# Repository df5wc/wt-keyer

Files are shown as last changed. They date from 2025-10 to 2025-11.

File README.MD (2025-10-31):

# Walkie-Talkie Keyer

So, hier isser: Der Walkie-Talkie Keyer. Das Projekt, an dem ich die letzten
Wochen nebenher rumgepusselt habe. Es ist eine komplette Hardware zum Betrieb
eines Handfunkgeräts als CW Station.

## Noch nie gestellte Fragen und ein paar Antworten:

### Was macht das Gerät?

CW über FM.

### Das kann ein Piepser, den ich ans Funkgerät halte. Wieso eine extra Hardware?

Der Walkie-Talkie Keyer übernimmt die komplette Steuerung. Er schaltet beim
ersten Zeichen das Handfunkgerät auf Sendung, generiert lokal einen Mithörton
und gibt die Morsezeichen auf das Funkgerät um wenige 100ms zeitverzögert aus.
Damit hat das Funkgerät Zeit, auf Sendung zu schalten. Mit dem Walkie-Talkie
Keyer ist CW mit einer Handfunke ähnlich komfortabel wie mit einem Gerät, das
CW native unterstützt: Einfach losmorsen. Das Gerät schaltet automatisch auf
Sendung und nach dem letzten Zeichen wieder zurück.

### Wofür braucht man das?

Ich habe es primär gebaut um auf dem Congress TOTA in CW machen zu können,
weil ich dort vermutlich nur ein Handfunkgerät haben werde. Der Walkie-Talkie
Keyer funktioniert aber nicht nur im Amateurfunk, sondern kann auch einfache
PMR Funkgeräte ansteuern und eignet sich deshalb auch zur Ausbildung oder als
Spaßprojekt für Kids. Der Keyer kann im Prinzip auch "große" Funkgeräte
ansteuern, solange diese PTT gegen Masse schalten und dafür keine hohen
Ströme/Spannungen notwendig sind.

### Gab's das nicht schon mal?

Ja, das gab's schon mal. Burkhard John (DK5JG) hat 2006 eine ähnliches Projekt
vorgestellt, den "FM-Keyer". Von diesem Gerät stammen einige der Ideen.
Schaltung, Software und Board des Walkie-Talkie Keyers sind aber komplett neu
und von mir.

### Paddle oder Handtaste?

Der Keyer kann beides, mit Handtaste ist aber keine Konfiguration möglich. Da
alle Einstellungen (bis auf "Handtaste oder Paddle") ausfallsicher gespeichert
werden, sollte das aber kein großes Problem sein. Nachdem die Konfiguration
mit einem Paddle durchgeführt wurde, kann mit genau diesen Einstellungen auch
eine Handtaste verwendet werden.

### Wie wird eine Handtaste erkannt?

Für ein Paddle wird ein 3,5 mm Stereo Klinkenstecker verwendet, für eine
Handtaste derselbe Stecker in Mono. Durch den Mono Stecker wird das rechte
Paddle ("Dah") an Masse gelegt. Das erkennt der Keyer beim Start und schaltet
direkt auf Handtaste um. Alternativ kann das rechte Paddle beim Start gedrückt
werden, oder mit dem "SK" Kommando (siehe unten) von Paddle auf Handtaste
umgeschaltet werden.

Die Einstellung "Handtaste" bleibt erhalten, bis der Keyer stromlos gemacht
wird. Ein Rückschalten durch Kommando ist nicht möglich.

### Wie bediene ich den Keyer?

Der Keyer benötigt externe 5V aus einem USB Port (Handy oder Power Bank). Er
wird auf der einen Seite mit dem Handfunkgerät verbunden. Auf der anderen
Seite wird die Taste angeschlossen. Neben der Einstellung für die Lautstärke
an der Seite gibt es an der Unterseite noch zwei Potis mit denen die Pegel für
das Handfunkgerät eingestellt werden können. Sie sollten bei der ersten
Inbetriebnahme auf jeweils 1/4 im Uhrzeigersinn eingestellt und dann nach
Gehör justiert werden. Bei Verwendung eines anderen Funkgeräts oder großen
Änderungen der Tonhöhe kann eine Nachjustierung notwendig sein.

Danach kann im Prinzip schon losgemorst werden. Zur Einstellung gibt es die
Taste &lt;Cmd&gt;. Wenn sie gedrückt und gehalten wird, können dem Keyer
Kommandos in CW gegeben werden. Hier ist die Liste der Kommandos:

* D?             query the tx delay
* Dnnn           set tx delay in ms
* IA             activate iambic A
* IB             activate iambic B
* IP             activate plain iambic mode
* M?1            query cw memory 1
* M?2            query cw memory 2
* M1...          program cw memory 1
* M2...          program cw memory 2
* O?             query tx off delay in dits
* Onn            set tx off delay in dits
* SK             switch to straight key
* SWD            disable paddle swap
* SWE            enable paddle swap
* T?             query the tone frequency
* TMD            disable training mode (TX)
* TME            enable training mode (no TX)
* Tnnn           set a tone frequency
* V?             query the software version number
* W?             query the keyer speed
* Wnn            set the keyer speed in wpm

Die Kommandos werden jeweils mit einem hohen Ton quittiert, wenn sie
erfolgreich ausgeführt wurden. Bei einem Fehler (oder einem unbekannten
Kommando) erfolgt eine Fehlerquittung (niedriger Ton).

Alle Einstellungen werden ausfallsicher gespeichert und stehen deshalb nach
dem nächsten Start genau so wieder zur Verfügung.

### Wie funktioniert das mit den CW Speichern?

Der Keyer verfügt über zwei Speicherplätze für Nachrichten in Morsecode. Diese
können über die Kommandos "M1" und "M2" programmiert und mit den Tasten
&lt;1&gt; und &lt;2&gt; abgerufen werden. Während ein Speichertext ausgegeben
wird, kann mittels Druck auf einen beliebigen Knopf oder Betätigung der
Morsetaste die Ausgabe abgebrochen werden.

Für die Programmierung wird &lt;Cmd&gt; gedrückt und "M1" oder "M2" mit dem
Paddle gegeben. Dann folgt der zu speichernde Text. Eine Pause von mindestens
2 Sekunden beendet die Eingabe mit einem Quittungston.

Um Speicherplatz zu sparen, werden alle Zeiten auf volle Vielfache der für ein
"Dit" benötigten Zeit gerundet. Der benötigte Speicherplatz pro Element mit
folgender Pause (also "Dit" oder "Dah") beträgt 1 Byte. Insgesamt stehen etwa
200 Bytes pro Speicherplatz zur Verfügung. Wird die maximale Länge eines
Speichers bei der Eingabe überschritten, erfolgt eine Fehlerquittung und der
Text wird nicht gespeichert. Die Programmierung kann auch durch Loslassen der
&lt;Cmd&gt; Taste vorzeitig abgebrochen werden (z.B. bei Fehltastung). Der
bereits gespeicherte Text bleibt dann erhalten.

### Wieso erfolgt die Tonausgabe des Handfunkgeräts über den Keyer?

Das ist bei Handfunkgeräten mit Kenwood "Norm" für den Anschluß eines externen
Mikrofons leider zwingend. Bei dieser Beschaltung werden zwei Stecker
verwendet, einer für Mikrofon/PTT, der andere für den Lautsprecher. Der
Stecker für Mikrofon/PTT führt aber keine Masse! Will man also PTT gegen Masse
schalten, muss zwingend auch der Lautsprecheranschluß verwendet werden. Dadurch
wird aber der interne Lautsprecher des Geräts abgeschaltet. Folglich muss die
Ausgabe über das angeschlossene Gerät erfolgen.

Wird eine andere Anschlußbeschaltung verwendet (von mir nicht getestet), dann
kann - falls das gewünscht ist - der "Speaker" Eingang am DIN Stecker des
Keyers einfach auf Masse gelegt, und der interne Lautsprecher des Geräts
verwendet werden. Der Mithörton kommt dann aus dem Lautsprecher des Keyers,
das Empfangssignal aus dem Lautsprecher des Funkgeräts.

### Welche Funkgeräte wurden getestet?

Ich habe den Keyer mit meinem Wouxun KG-UV6D und mit zwei verschiedenen PMR
Funkgeräten getestet. Alle diese Geräte hatten die Kenwood Anschlußbelegung.
Andere Anschlüsse sollten funktionieren, wenn PTT gegen Masse geschaltet wird
und keine hohen Ströme fliessen. Wenn keine Ausgabe des Empfangssignals über
die Keyer Hardware erfolgen soll, dann ist der entsprechende Eingang des
Keyers am DIN Stecker auf Masse zu legen.

### Ich habe ein Problem, wieso kann ich kein Issue anlegen?

Das Repository auf Github dient nur der Veröffentlichung, nicht der
Entwicklung. Für die Entwicklung wird ein anderes Repository verwendet.
Deshalb können auf Github keine Issues angelegt werden. Bei Problemen bitte
ich darum, mich per Mail zu kontaktieren.

### Gibt es bekannte Probleme?

Beim Prototyp hatte ich teilweise Probleme mit Einstrahlungen durch das
Handfunkgerät. Ich empfehle, ein abgeschirmtes Kabel für die Verbindung zum
Funkgerät zu verwenden und evtl. die Ferritperlen auf dem Board gegen kleine
Induktivitäten auszutauschen und/oder an der Stelle noch mit 100pF
abzublocken. Sobald mehr Erfahrungen vorliegen werde ich ggf. entsprechende
Änderungen der Schaltung vornehmen.

Die beiden Trimmer RV1 und RV2 werden von der Unterseite des Boards aus
bedient und haben deshalb die falsche Drehrichtung: Rechtsanschlag ist
Minimum, Linksanschlag ist Maximum.

### Ich kann mir das nicht vorstellen. Wie sieht der Keyer denn aus?

Hier sind Bilder vom aufgebauten Keyer und von einem kompletten Setup:

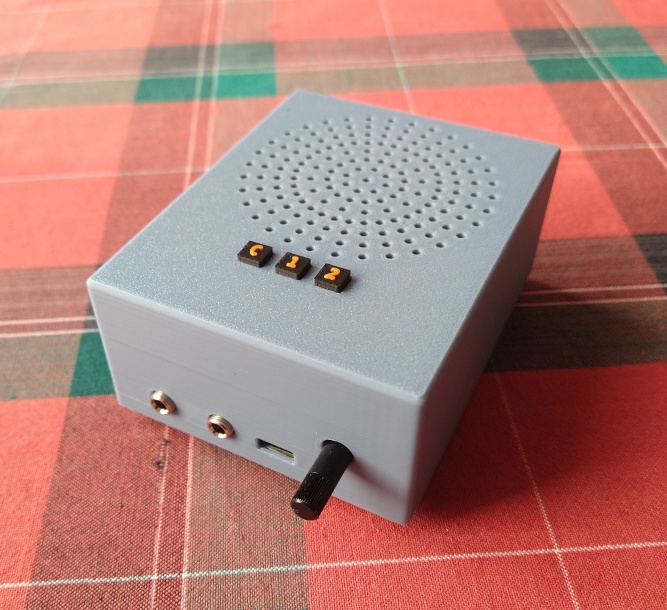
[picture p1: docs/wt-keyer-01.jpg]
Keyer

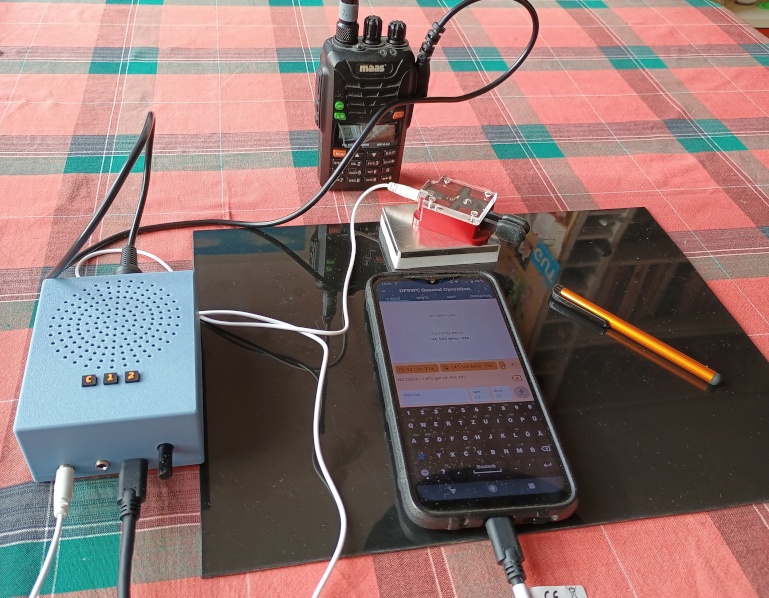
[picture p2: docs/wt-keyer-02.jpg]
Setup


### Wo gibt's den Keyer zu kaufen?

Gar nicht (zumindest bei mir). Von mir gibt es

  - den Schaltplan,
  - einen PCB Entwurf,
  - die Software,
  - OpenSCAD Sourcen und STL Datei für das Gehäuse,
  - und eine minimale Doku

auf GitHub. Mit dabei ist eine Teileliste mit (größtenteils und ohne Garantie)
Reichelt Bestellnummern.

Wenn genug Interesse besteht, kann ich nochmals einen Satz Platinen fertigen
lassen und - solange übrig sind - welche abgeben. Ggf. mit programmierter AVR
CPU. Ich vertreibe aber keine Fertiggeräte oder Bausätze. Falls das jemand
machen will habe ich aber nichts dagegen.

### Ok, ich will bauen! Wie lege ich los?

Hier gibt es mehr Infos zum Aufbau:

* Schaltplan
* Teileliste
* Aufbauhinweise

### Was gibt es sonst zu beachten?

Die Lizenz erlaubt so ziemlich alles, bis darauf die Entwürfe als eigene
auszugeben. Für Schäden beim Nachbau übernehme ich keine Haftung.

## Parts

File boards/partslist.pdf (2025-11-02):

Please note that this list is incomplete and partially untested! Use it at your own risk!

Count | References | Description | Source | Order Number | Alternative
3 | C13,C18,C21 | Kondensator 100μF/25V | Reichelt | RAD 100/25
9 | C5,C6,C7,C8,C10,C11,C14,C15,C19 | Kondensator 100nF, MKS02 | Reichelt | MKS02-63 100N
1 | C17 | Kondensator 47nF, MKS02 | Reichelt | MKS02-63 47N
5 | C1,C2,C3,C4,C16 | Keramik-Kondensator 100nF | Reichelt | Z5U-2,5 100N
4 | C9,C12,C20,C22 | Keramik-Kondensator 10nF | Reichelt | Z5U-2,5 10N
1 | Conn1 | Stiftleiste 2x3, RM 2,54 | Reichelt | MPE 087-2-006 | BKL 10120172
1 | F1 | Keramik-Resonator 8MHz | Reichelt | CST 8,00
8 | FB1,FB2,FB3,FB4,FB5,FB6,FB7,FB8 | Ferritperle | Aliexpress | https://de.aliexpress.com/item/10000063621565.html
1 | IC1 | AVR ATMega8 PDIP-28 | Reichelt | ATMEGA 8L8 DIP | ATMEGA 8-16 DIP
1 | IC2 | LM386-1, NF Verstärker IC | Reichelt | LM 386 DIP
1 | J1 | Printstecker, gerade, 2-polig | Reichelt | PSS 254/3G
1 | J2 | Printstecker, gerade, 3-polig | Reichelt | PSS 254/2G
2 | J3,J5 | 3.5mm Klinkenbuchse, Stereo | Reichelt | EBS 35
1 | J4 | Diodenbuchse 5-pol | Reichelt | MABP 5S
1 | J6 | USB Buchse 6-pol horizontal | Aliexpress | https://de.aliexpress.com/item/1005007419369264.html
1 | LS1 | Lautsprecher 8Ω, 0.5W | Reichelt | LSM-66F
1 | P1 | Potentiometer 10K linear | Reichelt | RK09K111-LIN10K
1 | Q1 | 2N3904 o.ä. | Reichelt | 2N 3904
4 | R1,R9,R10,R15 | Widerstand 10kΩ 5%, 250mW | Reichelt | 1/4W 10K
6 | R2,R3,R4,R5,R6,R7 | Widerstand 1.5kΩ 5%, 250mW | Reichelt | 1/4W 1,5K
1 | R8 | Widerstand 47kΩ 5%, 250mW | Reichelt | 1/4W 47K
1 | R11 | Widerstand 1kΩ 5%, 250mW | Reichelt | 1/4W 1,0K
1 | R12 | Widerstand 15kΩ 5%, 250mW | Reichelt | 1/4W 15K
1 | R13 | Widerstand 10Ω 5%, 250mW | Reichelt | 1/4W 10
1 | R14 | Widerstand 4.7kΩ 5%, 250mW | Reichelt | 1/4W 4,7K
1 | RV1 | Trimpoti 2.5kΩ linear | Reichelt | PT 10-L 2,5K
1 | RV2 | Trimpoti 500Ω linear | Reichelt | PT 10-L 500
3 | SW1,SW2,SW3 | Taster | Reichelt | DIP DTS-65K
1 | - | Kupplungs-Leergehäuse, 2-polig | Reichelt | PSK 254/2W
1 | PL4 | Kupplungs-Leergehäuse, 3-polig | Reichelt | PSK 254/3W
1 | - | Crimpkontakte | | Reichelt | PSK-KONTAKTE
1 | - | IC-Sockel 28-pol. | | Reichelt | GS 28-S
1 | - | IC-Sockel 8-pol. | | Reichelt | GS 8
1 | PL1,PL2 | Anschlußkabel Walkie-Talkie | Aliexpress | https://de.aliexpress.com/item/1005007107655534.html
1 | PL3 | DIN Stecker 5-pol 180° | Reichelt | MAS 50S
4 | - | Gummifüße 8mm | , 2mm hoch ⌀ | Aliexpress | https://de.aliexpress.com/item/1005005315398342.html
1 | - | Alternative USB Buchse, Einbau | Aliexpress | https://de.aliexpress.com/item/1005007579249404.html

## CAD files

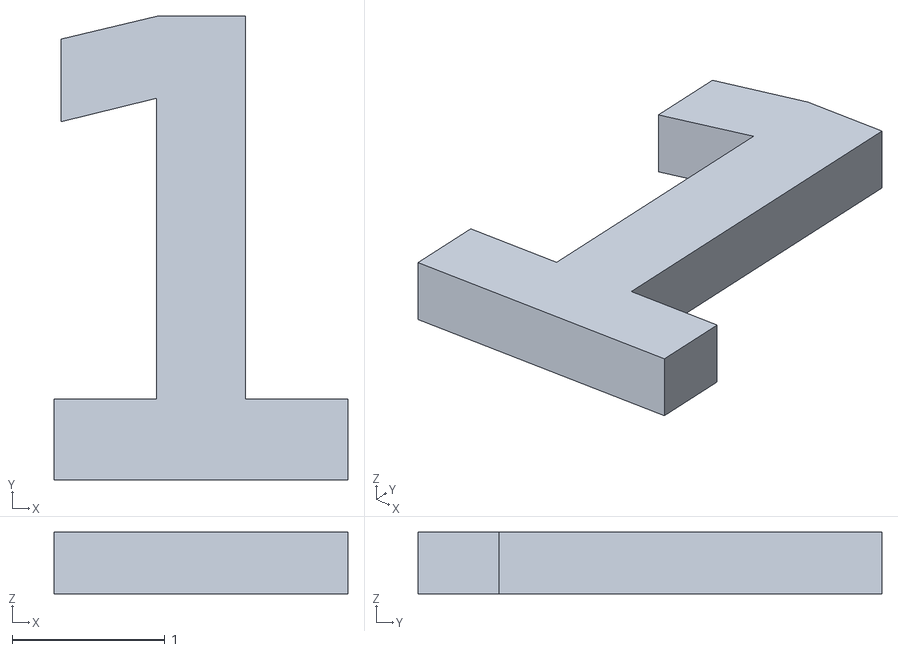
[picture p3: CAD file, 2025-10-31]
case/wt-keyer-button-label-1.stl
1.93 x 3.04 x 0.405

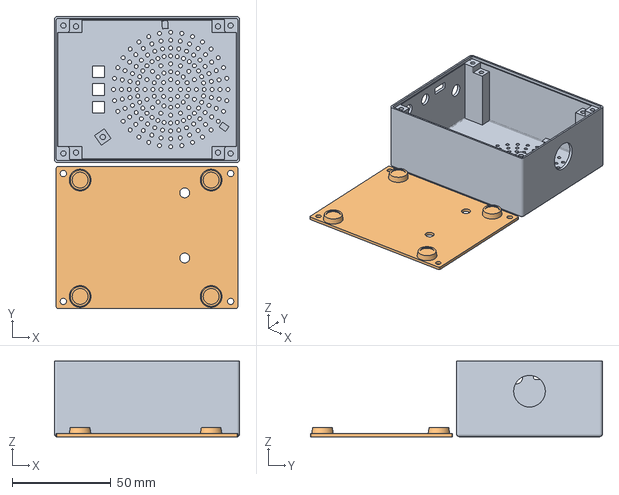
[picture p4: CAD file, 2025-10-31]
case/wt-keyer-case.3mf
94.0 x 148.0 x 38.3 mm
wt-keyer-case-upper.stl
wt-keyer-case-lower.stl

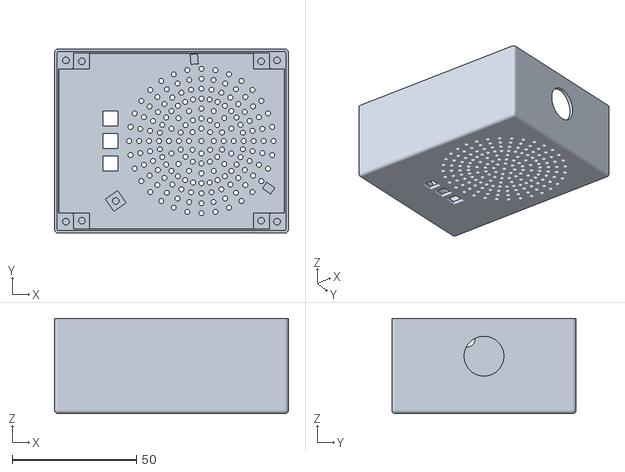
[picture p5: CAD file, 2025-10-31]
case/wt-keyer-case-upper-ext-usb.stl
94.0 x 74.0 x 38.3

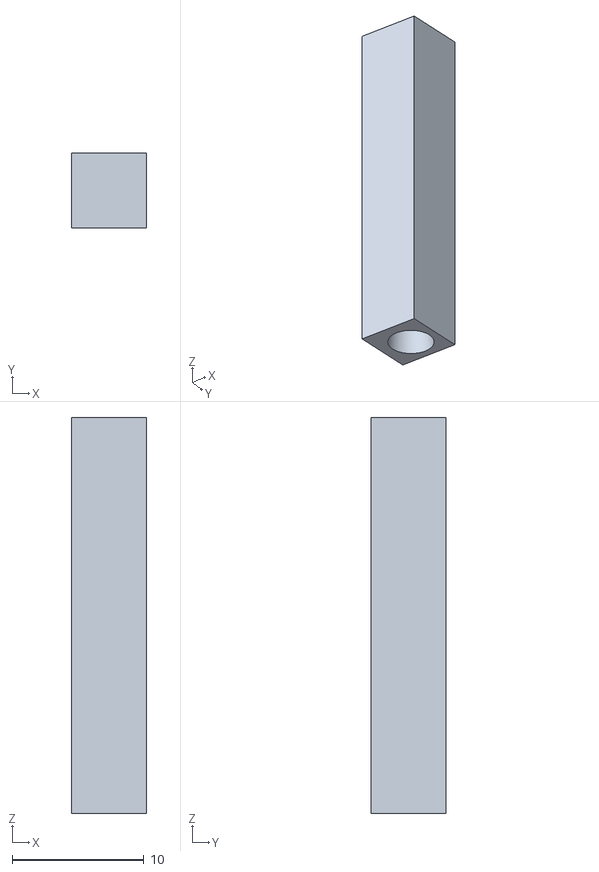
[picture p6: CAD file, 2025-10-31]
case/wt-keyer-button.stl
5.70 x 5.70 x 30.1

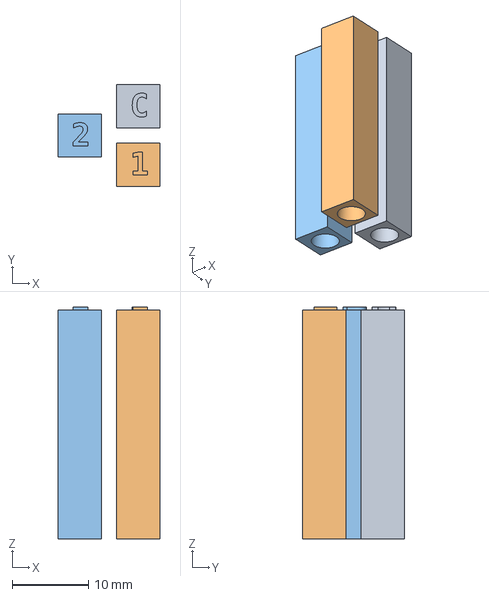
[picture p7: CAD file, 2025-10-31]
case/wt-keyer-buttons.3mf
13.4 x 13.4 x 30.5 mm
wt-keyer-case-button x 3

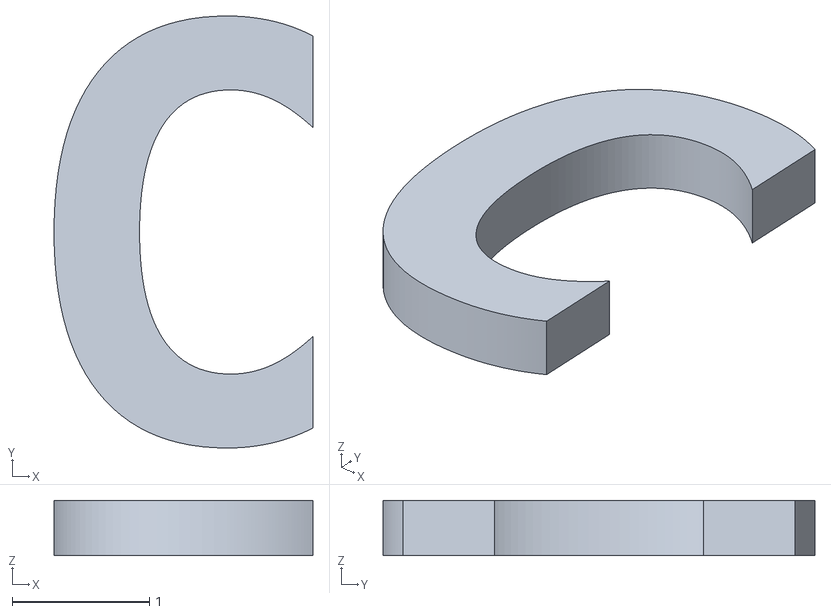
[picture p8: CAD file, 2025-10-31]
case/wt-keyer-button-label-c.stl
1.89 x 3.15 x 0.405

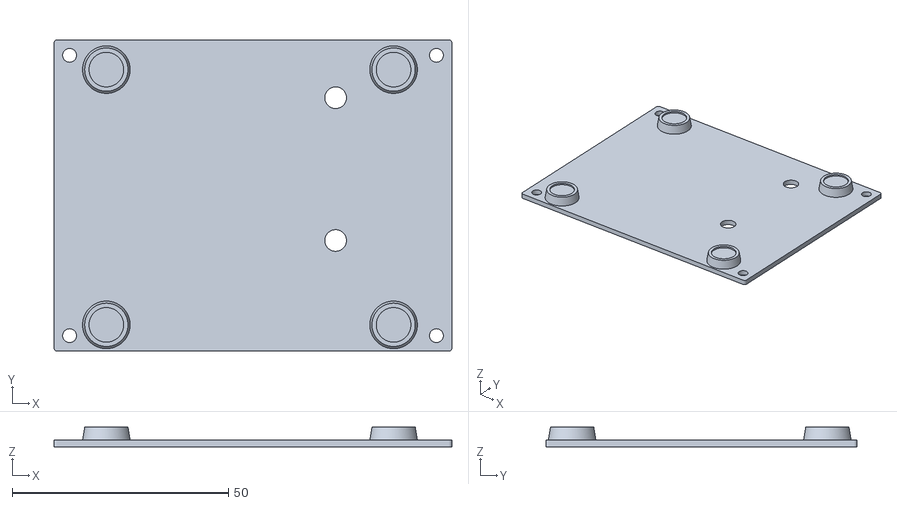
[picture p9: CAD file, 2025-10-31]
case/wt-keyer-case-lower.stl
92.0 x 72.0 x 4.60

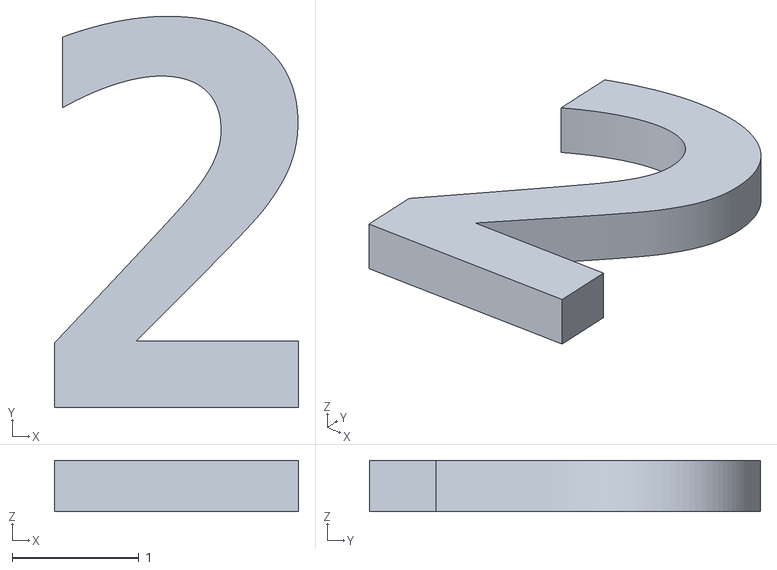
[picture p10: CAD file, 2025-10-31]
case/wt-keyer-button-label-2.stl
1.93 x 3.09 x 0.405

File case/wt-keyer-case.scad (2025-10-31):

/* Which object to generate:
 * 0 = upper part with usb breakout on the pcb
 * 1 = upper part with separate usb breakout
 * 2 = lower part
 * 3 = button prolongation
 * 4 = button label "C"
 * 5 = button label "1"
 * 6 = button label "2"
 */
what = 0;

/* Inner width of the case */
wcase = 70;

/* Inner length of the case */
lcase = 90;

/* Height of the board support: Speaker + components */
hpcbsupport = 20.5 + 11;

/* Inner height of the case.
 * Speaker + components + board + free space.
 */
hcase = hpcbsupport + 1.6 + 2;

/* Height of the lid support */
hlidsupport = hcase;

/* Gap between board and case */
gap = 0.4;

/* Radius for case edges */
rcase = 1.5;

/* Speaker diameter */
dspeaker = 66;

/* Wall width */
wall = 1.6;

/* Groove width */
groove = 0.6;

/* Screw hole diameter for self cutting screws */
mountinghole = 2.7;

/* Screw hole diameter for lid screws */
lidhole = 3.2;

/* Lower diameter of the feet */
dfoot = 11.0;

/* Height of the feet */
hfoot = 3.0;

/* Trimmer hole diameter */
trimmerhole = 5.0;

/* Button holes */
buttonhole = 6.0;

/* Hidden */
$fn  =  100;
eps  =  0.005;

/* Trimmer position #1 */
xtrimmer1 = 64.5;
ytrimmer1 = 58.0;

/* Trimmer position #2 */
xtrimmer2 = 64.5;
ytrimmer2 = 25.0;

/* Button position #1 */
xbutton1 = 20.5;
ybutton1 = 44;

/* Button position #2 */
xbutton2 = 20.5;
ybutton2 = 35;

/* Button position #3 */
xbutton3 = 20.5;
ybutton3 = 26;

/* Height of button prolongation. Switches are 9mm high, 5mm is overlap. */
hbutton = hpcbsupport + wall - 9.0 + 6.0;

/* Paddle jack position */
xpaddle = 13.0;
ypaddle = hpcbsupport - 3.05;
paddlehole = 6.5;

/* Headphone jack position */
xheadphones = 28.2;
yheadphones = hpcbsupport - 3.05;
headphoneshole = 6.5;

/* USB jack position */
xusb = 41.6;
yusb = hpcbsupport - 0.0;
usbholew = 9.0;
usbholeh = 4.0;

/* Volume control position */
xvolume = 56.0;
yvolume = hpcbsupport - 10.0;
volumehole = 7.0;

/* Rig control socket position */
xrigctrl = 35.0;
yrigctrl = hpcbsupport - 10.0;
rigctrlhole = 16.0;


module cylinder_outer(height, r1, r2){
    fudge = 1/cos(180/$fn);
    cylinder(h=height,r1=r1*fudge, r2=r2*fudge);
}

module roundedplate(x, y, z, rad = 0.75) {
    linear_extrude(height = z) {
        hull() {
            translate([0.75, 0.75, 0]) circle(r = 0.75);
            translate([x - 0.75, 0.75, 0]) circle(r = 0.75);
            translate([x - 0.75, y - 0.75, 0]) circle(r = 0.75);
            translate([0.75, y - 0.75, 0]) circle(r = 0.75);
        }
    }
}

module roundedcube(x, y, z, rad = 0.75) {
    hull() {
        translate([    rad,     rad,     rad]) sphere(rad);
        translate([x - rad,     rad,     rad]) sphere(rad);
        translate([    rad, y - rad,     rad]) sphere(rad);
        translate([x - rad, y - rad,     rad]) sphere(rad);
        translate([    rad,     rad, z - rad]) sphere(rad);
        translate([x - rad,     rad, z - rad]) sphere(rad);
        translate([    rad, y - rad, z - rad]) sphere(rad);
        translate([x - rad, y - rad, z - rad]) sphere(rad);
    }
}

module label(text, ha = "center", va = "center") {
    color("orange") {
        translate([0, 0, -eps]) {
            linear_extrude(0.4 + eps) {
                //text(text, size=3, font="Liberation Mono:style=Bold", halign=ha, valign=va);
                //text(text, size=3, font="Arial:style=Bold", halign=ha, valign=va);
                text(text, size=3.0, font="Bitstream Vera Sans Mono:style=Bold", halign=ha, valign=va);
            }
        }
    }
}

module usb_breakout() {
    translate([-usbholew/2, -usbholeh/2, -eps]) {
        roundedplate(usbholew, usbholeh, wall+2*eps, 1.0);
    }
}

module usb_panel_breakout() {
    l = 9;
    h = 4;
    w = 15.8;
    hole = 2.5;
    translate([-l/2, -h/2, -eps]) {
        roundedplate(l, h, wall+2*eps, 1.0);
    }
    translate([-w/2, 0, -eps]) {
        cylinder_outer(wall + 2*eps, hole/2, hole/2);
    }
    translate([w/2, 0, -eps]) {
        cylinder_outer(wall + 2*eps, hole/2, hole/2);
    }
}

module support() {
    lscrew = 12.0;
    difference() {
        union() {
            translate([0, 0, -eps]) {
                linear_extrude(height = hpcbsupport + eps) {
                    polygon(points=[
                        [-eps, -eps],
                        [-eps, 12 + gap],
                        [6 + gap, 12 + gap],
                        [6 + gap, -eps],
                    ]);
                }
            }
            intersection() {
                translate([-rcase + gap - eps, -rcase -eps, hpcbsupport - eps]) {
                    roundedplate(6 + rcase + eps, 6 + rcase + eps, hlidsupport - hpcbsupport + 0*eps);
                }
                translate([- eps, -eps, hpcbsupport - eps]) {
                    cube([6 + gap + eps, 6 + eps, hlidsupport - hpcbsupport + 2*eps]);
                }
            }
        }
        translate([3.0 + eps, 3.0 + eps, hlidsupport - lscrew]) {
            cylinder_outer(lscrew + eps, mountinghole/2, mountinghole/2);
        }
        translate([3.0 + gap + eps, 9.0 + gap + eps, hpcbsupport - lscrew]) {
            cylinder_outer(lscrew + eps, mountinghole/2, mountinghole/2);
        }
    }
}

module speakerhook() {
    translate([-1.5, 2, 0]) {
        rotate([0, 270, 180])
        linear_extrude(height = 3) {
            /* The polygon might need a height adjustment depending
             * on the speaker and the print resolution.
             */
            polygon(points=[
                [0.0, 0.0], 
                [0.0, 2.0], 
                [1.9, 2.0], 
                [3.3, 4.0], 
                [3.3, 0.0]
            ]);
        }
    }
}

module speakerscrewholder() {
    translate([-3-eps, -3-eps, -eps]) {
        difference() {
            cube([6 + 2*eps, 6 + 2*eps, 5.5 + eps]);
            translate([3.0 + eps, 3.0 + eps, 0 - eps]) {
                cylinder_outer(5.5 + 3*eps, mountinghole/2, mountinghole/2);
            }
        }
    }
}

module speakerholders() {
    rotate([0, 0, 275]) {
        translate([0, dspeaker / 2, 0]) {
            speakerhook();
        }
    }
    rotate([0, 0, 145]) {
        translate([0, dspeaker / 2, 0]) {
            speakerhook();
        }
    }
    rotate([0, 0, 35]) {
        translate([0, 9, 0]) {
            translate([0, dspeaker / 2, 0]) {
                speakerscrewholder();
            }
        }
    }
}

module speakerholes() {
    for (angle = [0:11.25:360]) {
        rotate([0, 0, angle]) {
            if (dspeaker/2 > 29+2) {
                translate([29, 0, 0]) {
                    cylinder(wall + 2*eps, r1=1, r2=1);
                }
            }
            if (dspeaker/2 > 25+2) {
                translate([25, 0, 0]) {
                    cylinder(wall + 2*eps, r1=1, r2=1);
                }
            }
            if (dspeaker/2 > 21+2) {
                translate([21, 0, 0]) {
                    cylinder(wall + 2*eps, r1=1, r2=1);
                }
            }
            if (dspeaker/2 > 17+2) {
                translate([17, 0, 0]) {
                    cylinder(wall + 2*eps, r1=1, r2=1);
                }
            }
        }
    }
    for (angle = [0:22.5:360]) {
        rotate([0, 0, angle]) {
            translate([13, 0, 0]) {
                cylinder(wall + 2*eps, r1=1, r2=1);
            }
            translate([9, 0, 0]) {
                cylinder(wall + 2*eps, r1=1, r2=1);
            }
        }
    }
    for (angle = [0:45:360]) {
        rotate([0, 0, angle]) {
            translate([5, 0, 0]) {
                cylinder(wall + 2*eps, r1=1, r2=1);
            }
        }
    }
    cylinder(wall + 2*eps, r1=1, r2=1);
}
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

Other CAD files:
case/wt-keyer-case-ext-usb.3mf
case/wt-keyer-case-upper.stl

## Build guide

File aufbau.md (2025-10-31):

# Aufbau und Inbetriebnahme des Walkie-Talkie Keyers

## Gehäuse

Das Gehäuse besteht aus:

- Dem Oberteil, das es in zwei Varianten gibt, je nachdem ob die USB Buchse auf dem Board verwendet wird, oder nicht.
- Dem Unterteil.
- Den Verlängerungen für die Drucktaster.
- Die optionale Beschriftung für die Tasten.

Ich habe das Gehäuse mit einem BambuLab P2S in PLA gedruckt. Besitzer von
BambuLab Druckern können die bereitgestellten 3mf Dateien verwenden. Diese
enthalten alle Einstellungen, wie sie von mir vorgenommen werden. Ggf. ist das
Filament noch zu korrigieren.

Hinweise für Besitzer anderer Drucker: Der Ausdruck insbesondere des Oberteils
sollte mit einer höheren Auflösung erfolgen, damit die Halterungen für den
Lautsprecher und die Ausschnitte für die Druckschalter passen.

Die Beschriftungen der Verlängerungen für die Druckschalter habe ich mit einem
andersfarbigen Filament vorgenommen (schwarzes Gehäuse, orange Beschriftung).
Das funktioniert nur sinnvoll mit einem Drucker, der mehrfarbigen Druck
unterstützt. Ist das nicht der Fall kann entweder das Label in derselben Farbe
wie die Verlängerung gedruckt, und danach lackiert werden, oder die
Beschriftung wird weggelassen und die Tasten werden später mit Aufklebern
markiert. Ein manueller Filamentwechsel ist auch möglich, dazu ist aber ein
Eingriff in den Druckprozess notwendig.

Nach dem Ausdruck ist es evtl. sinnvoll, auf der Unterseite die Löcher für die
Trimmer zur Einstellung von Lautstärke und Mikrofonpegel zu markieren.

## Aufbau

### USB Buchse J6 / Stecker J1

> [!IMPORTANT]
> Die USB Buchse J6 ist ein SMD Bauteil. Wenn sie verwendet wird (siehe unten), dann muss sie **unbedingt** als erstes auf dem ansonsten leeren Board montiert werden. Danach sind alle 6 Anschlüsse mit dem Durchgangsprüfer auf Kurzschlüsse, insbesondere gegen Masse zu prüfen! Fehler die hier gemacht werden sind kaum noch zu korrigieren, sobald weitere Teile bestückt wurden!

Wer Probleme hat, die Buchse zu löten, kann stattdessen die beim Prototypen
verwendete Einbaubuchse verwenden. In diesem Fall werden die USB Buchse J6 und
der Widerstand R15 auf dem Board **nicht** bestückt. R15 muss statt auf dem
Board an der USB Einbaubuchse zwischen CC1 und Masse verlötet werden. Dabei
ist darauf zu achten, dass dieser nicht mit den Drucktastern kollidiert.
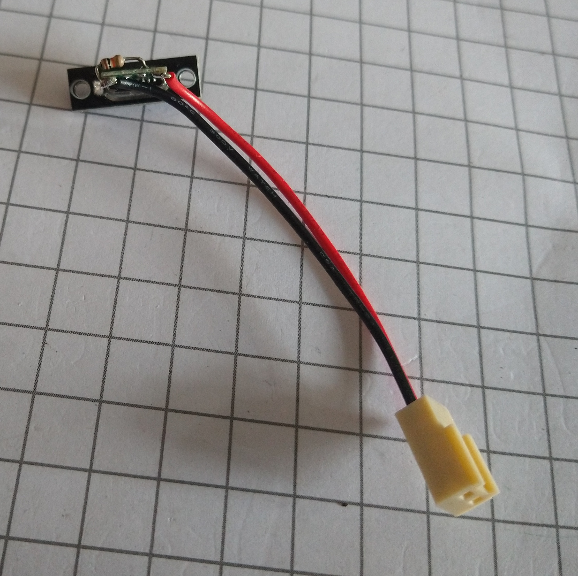
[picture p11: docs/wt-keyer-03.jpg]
Anschlusskabel mit R15
 Die Einbaubuchse wird (in
richtiger Polung!) mit J1 verbunden. Der Widerstand R15 kann auch weggelassen
werden, dann funktioniert die Stromversorgung aber nur über USB Netzteile,
nicht über Handys etc.

Wird die USB Buchse J6 bestückt, dann braucht J1 nicht unbedingt bestückt zu
werden. Eine bestückte Buchse erleichtert aber die Tests.

### Fassungen

Für die beiden ICs würde ich Fassungen empfehlen.

### Programmierstecker

> [!CAUTION]
> Der 6-polige Programmierstecker auf dem Board hat keine Markierung für Pin 1. Diese ist nur aus dem Platinenaufdruck ersichtlich, der aber durch den Einbau verdeckt wird. Deshalb ist es sinnvoll, Pin 1 des Steckers mit Edding o.ä. auf der Platine zu markieren, damit beim Programmieren der Stecker nicht falsch herum aufgesteckt wird.

Falls der Stecker bei Reichelt bestellt wird, würde ich empfehlen, nicht das
in der Teileliste angegebene, genau passende Teil "MPE 087-2-006" zu nehmen,
sondern eine längere Leiste (z.B. "BKL 10120172") und das passende Stück
abzutrennen. Die Leisten sind teilbar, und längere Leisten sind im Verhältnis
deutlich billiger als kürzere. Das gilt insbesondere, wenn mehrere Platinen
aufgebaut werden.

### Programmierung

Die Programmierung der AVR CPU bzw. die Schaltung der Fuses geht aus dem
Makefile hervor.

### MKS Kondensatoren

Die verwendeten MKS Kondensatoren in den NF Zweigen sind recht teuer (ca.
0,30€ pro Stück). Die Verwendung von Keramik-Kondensatoren ist wahrscheinlich
auch möglich, wurde aber von mir nicht getestet.

### Anschluß J3

Anstelle der in der Teileliste aufgeführten 3-poligen Buchsen/Stecker können
auch simple einreihige Stiftleisten mit passenden Stecker aus
ausgeschlachteten PCs verwendet werden. Die Polung ist beim Lautsprecher egal,
der Einbaustecker muss deshalb keinen Verpolungsschutz haben.

### Ferritperlen

Die Ferritperlen wurden von mir als Vorsichtsmaßnahme vorgesehen um die
Eintrahlfestigkeit zu erhöhen. Sie sind für die eigentliche Funktion des
Keyers nicht notwendig. Ein Test mit einem Aufbau ohne die Ferritperlen hat
tatsächlich einen Effekt gezeigt, deshalb sind diese weiterhin auf dem Board
vorhanden. Bei Verwendung des Keyers an einem Gerät mit abgesetzter Antenne
sollte es aber auch möglich sein, sie durch Drahtbrücken zu ersetzen.

Falls trotz der Ferritperlen Probleme mit Eintrahlung auftreten können
zusätzliche 100pF Kondensatoren gegen Masse jeweils vor und/oder nach den
Ferritperlen helfen. Die große Kupferfläche auf Ober- und Unterseite der
Platine ist Masse.

### DIN Stecker

Die Schaltung verwendet einen 5-poligen Stecker. Es können aber auch 7-polige
Buchsen bzw. Stecker verbaut werden, falls jemand diese in der Vorratskiste
hat. Die zusätzlichen Pins bleiben dann unbeschaltet.

### Transistor Q1

Der Transistor schaltet PTT gegen Masse. Es kann auch ein sonstiger
Kleinleistungstyp wie BC237 o.ä bestückt werden. Dabei ist darauf zu achten,
dass die Type aus der BC... Reihe eine andere Anschlußbelegung haben, als der
2N3904 und deshalb anders als im Bestückungsdruck ersichtlich bestückt werden
müssen.

### Lautsprecher

Für die Schraub-Befestigung wird ein kleiner Blechstreifen verwendet.
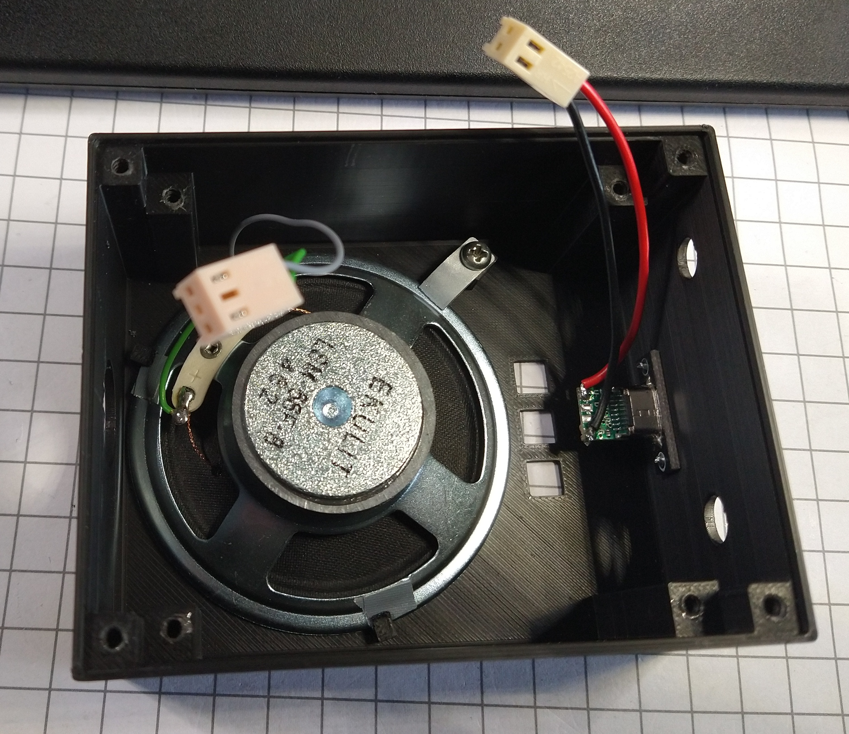
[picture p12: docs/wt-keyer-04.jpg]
Lautsprecher Einbau
 Auf ein eigenes Bauteil aus dem
3D Drucker habe ich verzichtet.

Die Haken für die Befestigung des Lautsprechers sind relativ kritisch in der
Bemaßung. Es kann deshalb sein, dass sie bei anderen Druckern oder einer
anderen Druckauflösung zu viel Raum lassen. Das läßt sich mit kleinen Streifen
Gewebeband zwischen Lautsprecher und Haken korrigieren.

Der verwendete Lautsprecher wurde bewusst recht groß gewählt um eine gute
Audio-Qualität zu gewährleisten. Es ist denkbar, hier auch kleinere bzw.
flachere Typen einzusetzen, was auch eine niedrigere Gehäuseform ermöglichen
würde. Dabei ist darauf zu achten, dass die Eigenresonanzfrequenz des
Lautsprechers möglichst tief ist, weil sonst unangenehme Resonanzen auftreten
können.

### USB Netzteile

Wird ein USB Netzteil zur Stromversorgung verwendet, dann kann es durch
mangelnde Siebung zu Geräuschen (üblicherweise ein leiser, hoher Ton) im Audio
kommen. Abhilfe kann ein besseres Netzteil, ein größerer Kondensator C13, oder
ein zusätzlicher Kondensator direkt an der USB Buchse schaffen.

### Tastenverlängerungen

> [!TIP]
> Die ausgedruckten "Verlängerungen" für die Drucktaster werden am besten erst gesteckt, wenn die Platine im Gehäuse montiert wurde. Wenn sie bereits vorher aufgesteckt werden, dann gestaltet sich das "Einfädeln" der Platine in die Gehäuseausbrüche etwas schwierig.

## Inbetriebnahme

### Bestückung prüfen

> [!NOTE]
> Bitte vor der Inbetriebnahme nochmals die Elektrolytkondensatoren und den Transistor Q1 auf richtige Polung prüfen! Die ICs sind vorerst nicht zu stecken.

### Stromversorgung prüfen

Nach Bestückung aller Bauteile **mit Ausnahme der beiden ICs** wird das Board
über den Stecker J1 und ein 5V Netzgerät mit einstellbarer Strombegrenzung mit
Strom versorgt. Die Strombegrenzung ist auf 10-20mA einzustellen. Nach dem
Einschalten darf kein messbarer Strom fliessen. Die Elektrolytkondensatoren
dürfen nicht warm werden.

An IC1 Pin 7 und IC2 Pin 6 müssen 5V gegen Masse (die große Fläche auf dem
Board, abzugreifen z.B. an den Löchern für die Befestigungsschrauben) zu
messen sein.

Wenn die USB-Buchse J6 bestückt ist: Verbindung zur Stromversorgung lösen und
stattdessen zuerst eine USB Stromversorgung und dann ein Handy an die USB
Buchse anschließen und jedesmal prüfen, ob an den ICs 5V anliegen.

### Erster Test

Den AVR programmieren und beide ICs in die Fassungen einsetzen.

> [!WARNING]
> Fuses nicht vergessen! Sonst ergeben sich seltsame Effekte.

Paddle anschliessen.

Den Lautstärkeregler ganz nach links drehen.

Die beiden Trimmer RV1 und RV2 aus Sicht auf die Bestückungsseite zuerst ganz
nach links und dann ca. 1/4 des Drehbereichs wieder nach rechts drehen.

Das Board über J1 an ein Netzgerät mit 5V anschliessen. Strombegrenzung auf
20mA stellen und einschalten. Der aufgenommene Strom beträgt knapp 10mA. Wenn
das ok ist, die Strombegrenzung auf 100mA erhöhen.

Rechtes Paddle drücken und den Lautstärkeregler langsam nach rechts drehen. Es
müssten "Dahs" zu hören sein. Linkes Paddle produziert "Dits".

Kopfhörer anschliessen und Lautstärke zurück drehen. Testen ob der Kopfhörer
funktioniert.

### Walkie-Talkie Anschluß

> [!NOTE]
> Die folgende Information bezieht sich auf Funkgeräte mit Kenwood Anschluss.

Stromversorgung abschalten, Anschlusskabel zum Funkgerät in das Board
einstecken. Kein Funkgerät anschliessen.

Das Verbindungskabel mit dem Durchgangsprüfer messen. Das ist recht einfach,
weil alle Kabel-Pins über Ferritperlen gehen, an denen sich das Signal recht
einfach abgreifen läßt.

- FB1 geht an den äußeren Ring des 3,5mm Steckers.
- FB2 geht an den mittleren Ring des 3,5mm Steckers.
- FB3 geht an den äußeren Ring des 2,5mm Steckers.
- FB4 geht an die Spitze des 2,5mm Steckers.
- Die Spitze des 3,5mm Steckers und der mittlere Ring des 2,5mm Steckers sind unbeschaltet.

Danach ein Funkgerät mit Kenwood Belegung anschliessen und einschalten. Ggf.
Dummy Load anschliessen. Wird zum Test der Squelch des Funkgeräts
freigeschaltet, dann muss das Audio Signal des Funkgeräts über den
Lautsprecher des Keyers ausgegeben werden. Es kann auch ein zweites Funkgerät
zur Generierung eines Audio-Signals verwendet werden. Die Lautstärke kann mit
RV2 so eingestellt werden, dass sie zur Lautstärke des Mithörtons passt.
Danach kann sie am Funkgerät geregelt werden.

Dann den Keyer tasten. Das Funkgerät muss auf Sendung und danach wieder auf
Empfang schalten.

Mit einem zweiten Funkgerät wird das gesendete Signal überprüft. Es hat eine
kleine Verzögerung gegenüber dem vom Keyer generierten Mithörton. Der Pegel
des Sendesignals kann mit RV1 geregelt werden und ist so einzustellen, dass
der maximale Hub nicht überschritten wird.

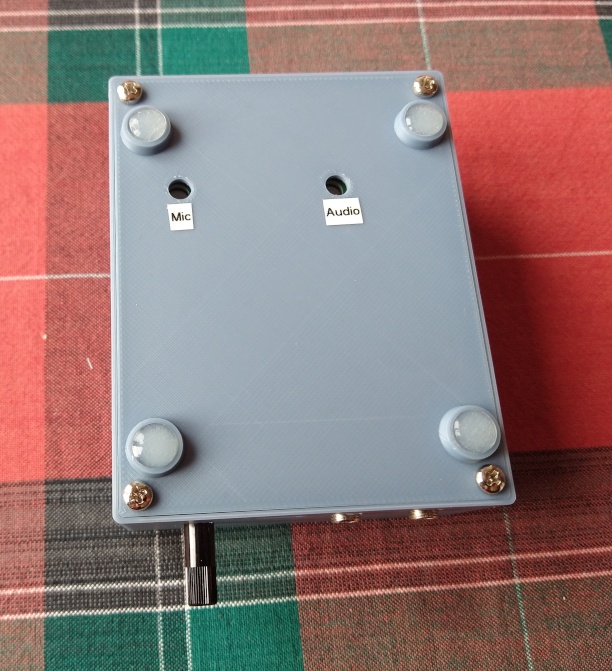
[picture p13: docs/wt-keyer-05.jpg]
Einstellregler auf der Unterseite


> [!TIP]
> Der Pegel des Sendesignals ist aufgrund des Tiefpasses etwas von der Frequenz des gesendeten Tons abhängig. Wer es besonders gut machen will, stellt erst die gewünschte Tonfrequenz und dann den Mikrofonpegel ein. Da der verwendete Hub aber unter dem maximalen liegen sollte und übliche Funkgeräte das Eingangssignal limitieren sollten in der Praxis auch bei einer späteren Änderung der Tonhöhe keine Probleme auftreten.

> [!WARNING]
> Auf V2 des Boards haben die beiden Trimmer bei Sicht auf die Unterseite die "falsche" Drehrichtung. Rechtsdrehung (im Uhrzeigersinn) ist Minimum.

### Einbau und Abschluß

Die Platine in das Gehäuse einbauen. Die Platine muss dazu zuerst schräg
eingesetzt und dann das Gehäuse mit etwas Kraft gebogen werden, damit der DIN
Stecker "reinflutscht". Die Verlängerungen für die Druckschalter stecken.
Gummifüße montieren. Gerät nochmals testen.

Das war's - viel Spaß mit dem Gerät!

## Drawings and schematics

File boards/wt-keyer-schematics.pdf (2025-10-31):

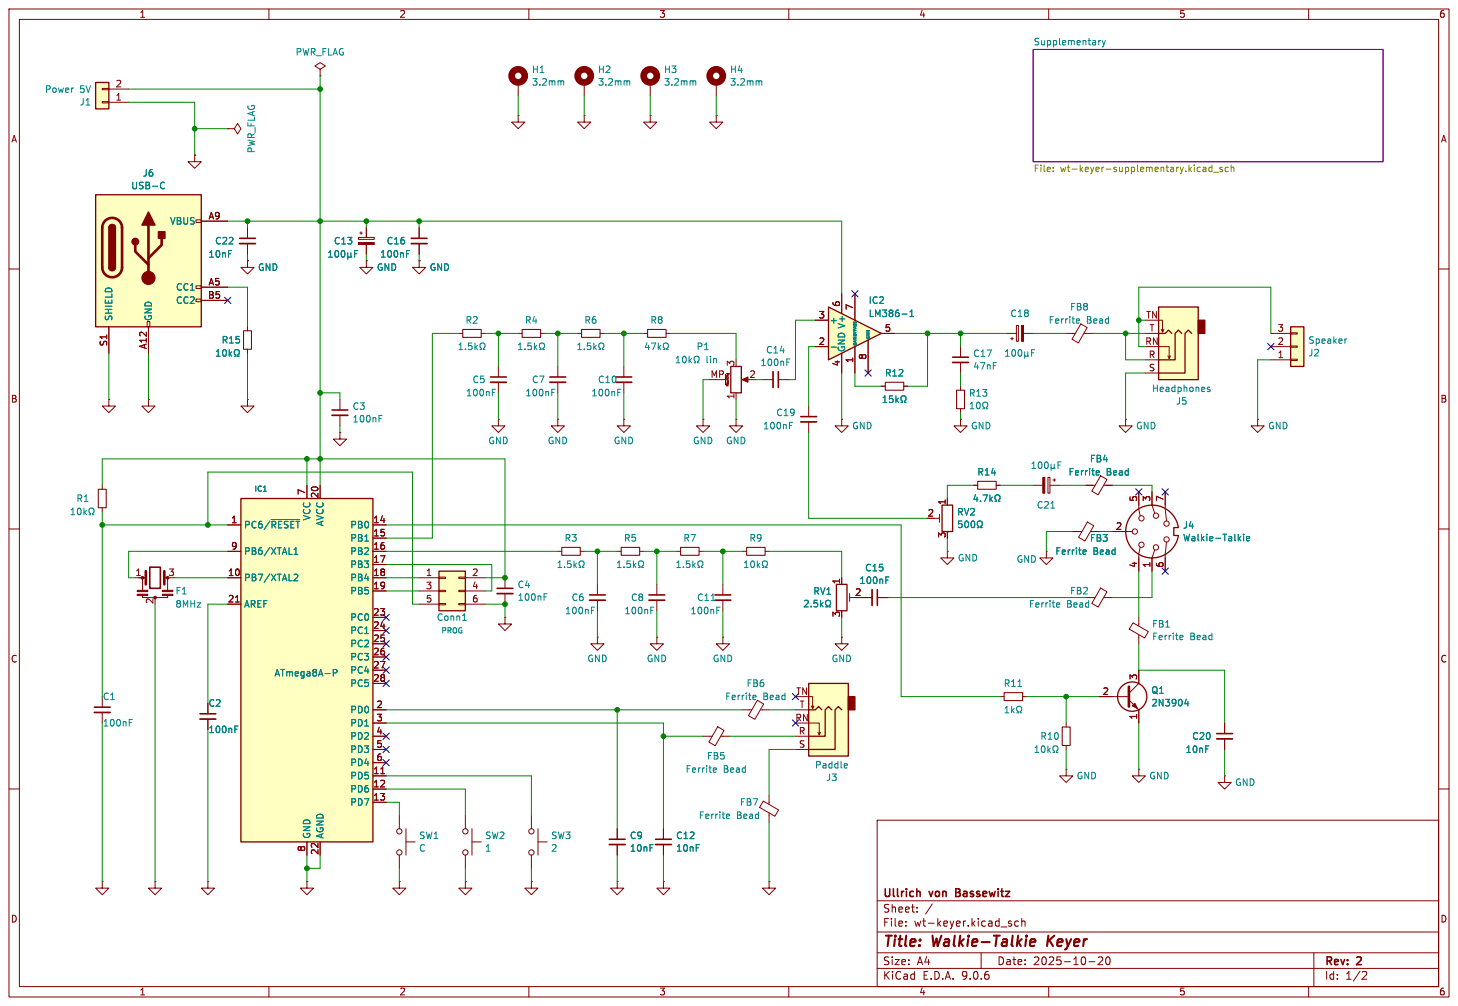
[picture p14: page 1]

þÿ10k!&lin GND GND

FB3 Ferrite Bead FB2 Ferrite Bead

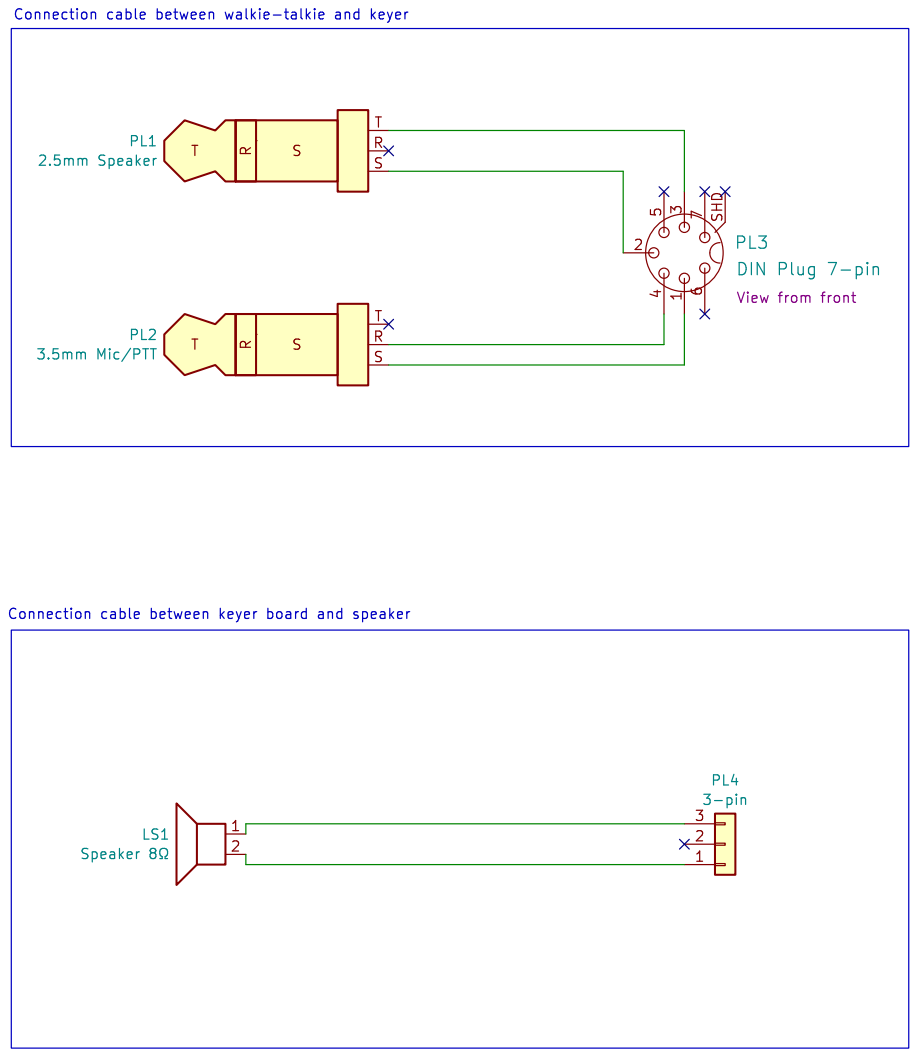
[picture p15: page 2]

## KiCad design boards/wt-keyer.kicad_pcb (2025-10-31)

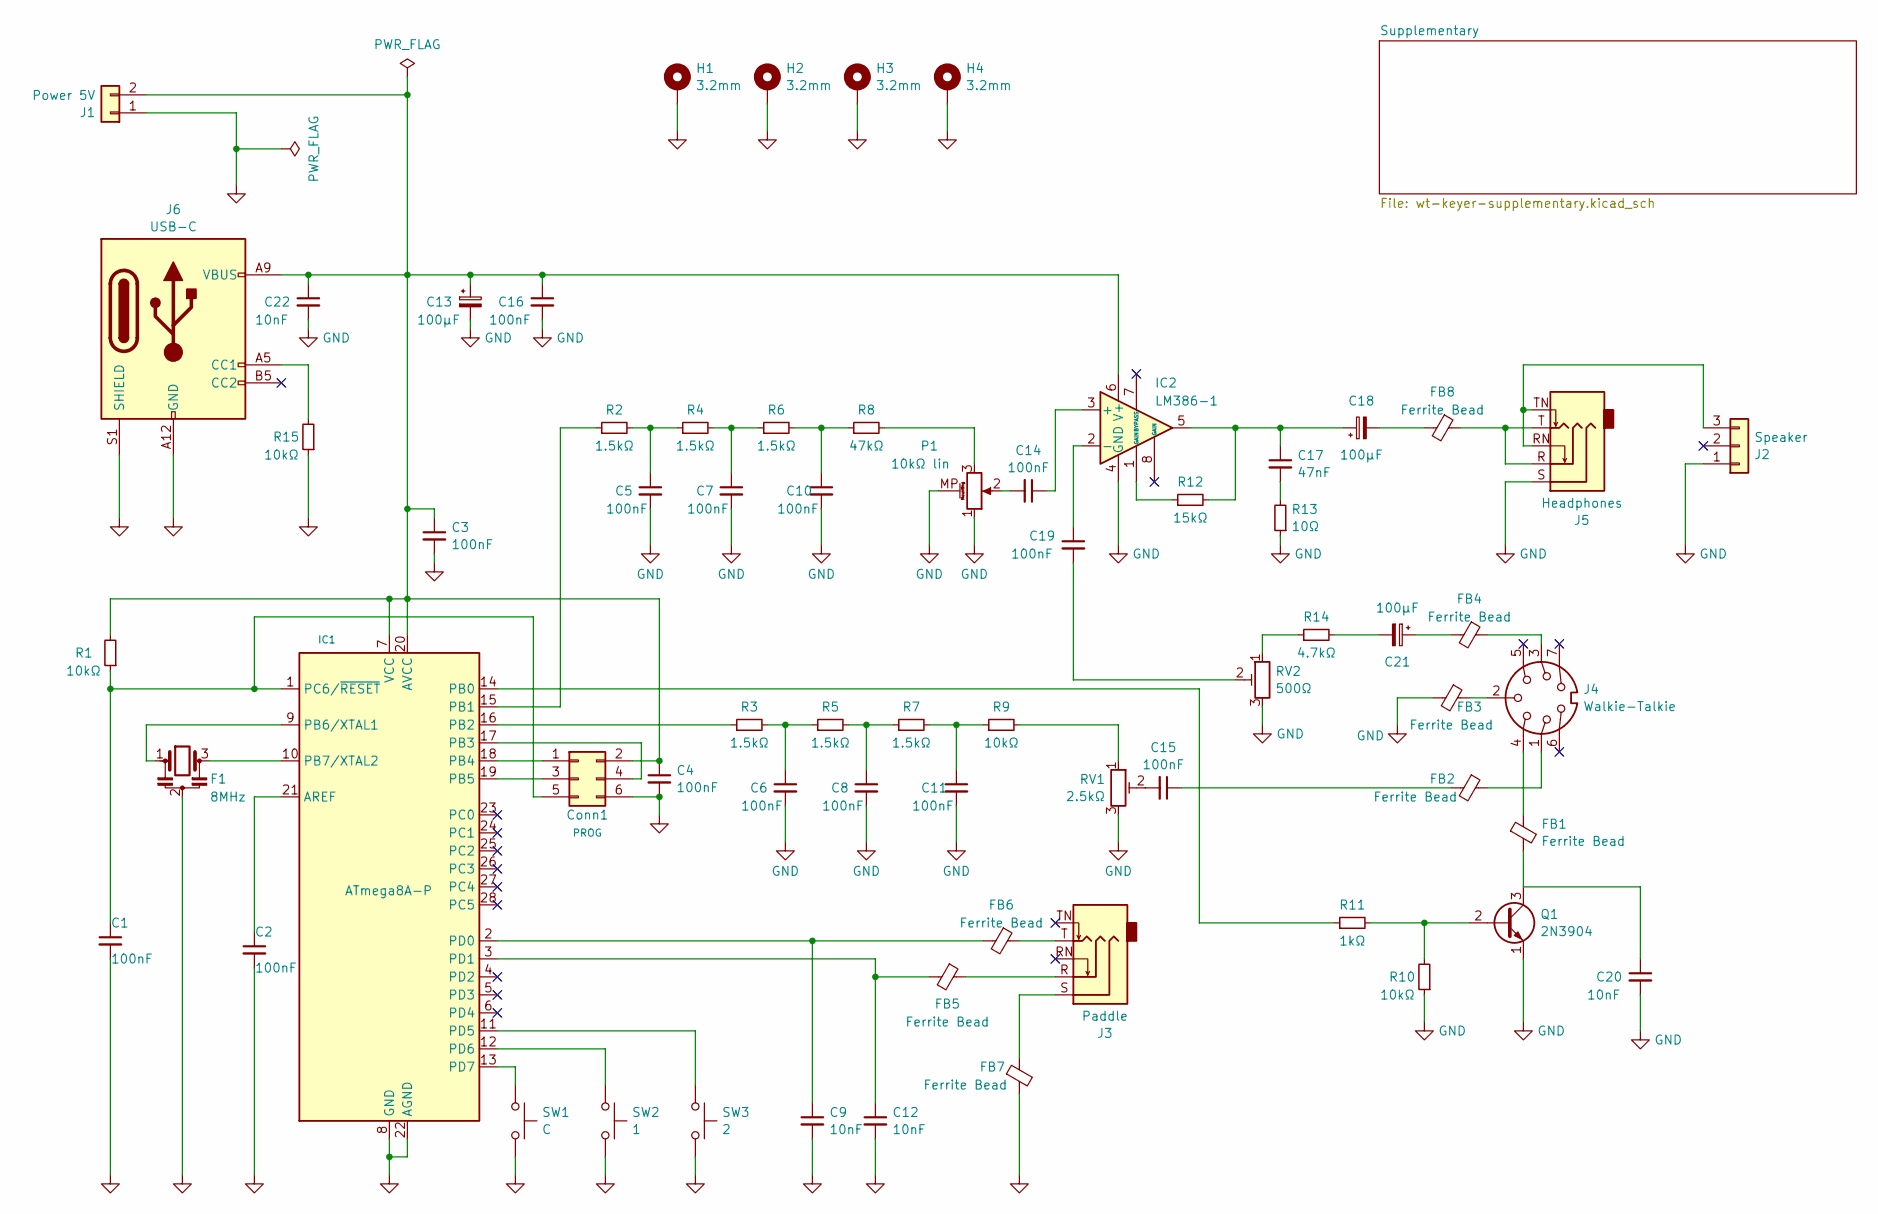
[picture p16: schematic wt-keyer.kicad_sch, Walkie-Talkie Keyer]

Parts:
C1, C2, C3, C4, C16: 100nF; C_Disc_D3.0mm_W1.6mm_P2.50mm
C5, C6, C7, C8, C10, C11, C14, C15, C19: 100nF; C_Rect_L4.6mm_W3.0mm_P2.50mm_MKS02_FKP02
C9, C12, C20, C22: 10nF; C_Disc_D3.0mm_W1.6mm_P2.50mm
C13, C18, C21: 100μF; CP_Radial_D5.0mm_P2.50mm
C17: 47nF; C_Rect_L4.6mm_W3.0mm_P2.50mm_MKS02_FKP02
Conn1: PROG; PinHeader_2x03_P2.54mm_Vertical
F1: 8MHz; Resonator-3Pin_W7.0mm_H2.5mm
FB1, FB2, FB3, FB4, FB5, FB6, FB7, FB8: Ferrite Bead; L_Axial_L9.5mm_D4.0mm_P2.54mm_Vertical_Fastron_SMCC
H1, H2, H3, H4: 3.2mm; MountingHole_3.2mm_M3_Pad_5.0mm_TopBottom
IC1: ATmega8A-P; DIP-28_W7.62mm
IC2: LM386-1; DIP-8_W7.62mm_Socket_LongPads
J1: Power 5V; FanPinHeader_1x02_P2.54mm_Vertical
J2: Speaker; FanPinHeader_1x03_P2.54mm_Vertical
J3: Paddle; Jack_3.5mm_Ledino_KB3SPRS_Horizontal
J4: Walkie-Talkie; DIN_7Pin_Horizontal
J5: Headphones; Jack_3.5mm_Ledino_KB3SPRS_Horizontal
J6: USB-C; USB_C_Receptacle_GCT_USB4125-xx-x-0190_6P_TopMnt_Horizontal
P1: 10kΩ lin; Potentiometer_Alps_RK09K_Single_Horizontal
Q1: 2N3904; TO-92_Inline
R1, R9, R10, R15: 10kΩ; R_Axial_DIN0207_L6.3mm_D2.5mm_P2.54mm_Vertical
R2, R3, R4, R5, R6, R7: 1.5kΩ; R_Axial_DIN0207_L6.3mm_D2.5mm_P2.54mm_Vertical
R8: 47kΩ; R_Axial_DIN0207_L6.3mm_D2.5mm_P2.54mm_Vertical
R11: 1kΩ; R_Axial_DIN0207_L6.3mm_D2.5mm_P2.54mm_Vertical
R12: 15kΩ; R_Axial_DIN0207_L6.3mm_D2.5mm_P2.54mm_Vertical
R13: 10Ω; R_Axial_DIN0207_L6.3mm_D2.5mm_P2.54mm_Vertical
R14: 4.7kΩ; R_Axial_DIN0207_L6.3mm_D2.5mm_P2.54mm_Vertical
RV1: 2.5kΩ; Potentiometer_Piher_PT-10-V10_Vertical
RV2: 500Ω; Potentiometer_Piher_PT-10-V10_Vertical
SW1: C; SW_PUSH_6mm_H4.3mm
SW2: 1; SW_PUSH_6mm_H4.3mm
SW3: 2; SW_PUSH_6mm_H4.3mm

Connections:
GND: C1.2, C2.2, C3.2, C4.2, C5.2, C6.2, C7.2, C8.2, C9.2, C10.2, C11.2, C12.2, C13.2, C16.2, C20.2, C22.2, Conn1.6, F1.2, FB3.2, FB7.2, H1.1, H2.1, H3.1, H4.1, IC1.8 (GND), IC1.22 (AGND), IC2.4 (GND), J1.1, J2.1, J5.S, J6.A12 (GND), J6.B12 (GND), J6.S1 (SHIELD), P1.1, P1.MP (MountPin), Q1.1 (E), R10.1, R13.1, R15.1, RV1.3, RV2.3, SW1.2, SW2.2, SW3.2
unnamed: C5.1, R2.2, R4.1
unnamed: C6.1, R3.2, R5.1
unnamed: C7.1, R4.2, R6.1
unnamed: C8.1, R5.2, R7.1
unnamed: C10.1, R6.2, R8.1
unnamed: C11.1, R7.2, R9.1
unnamed: C14.2, P1.2
unnamed: C15.1, FB2.2
unnamed: C15.2, RV1.2
unnamed: C17.1, C18.1, IC2.5, R12.2
unnamed: C17.2, R13.2
unnamed: C18.2, FB8.2
unnamed: C19.2, RV2.2
unnamed: C21.1, FB4.2
unnamed: C21.2, R14.2
unnamed: Conn1.1, IC1.18 (PB4)
unnamed: C3.1, C4.1, C13.1, C16.1, C22.1, Conn1.2, IC1.7 (VCC), IC1.20 (AVCC), IC2.6 (V+), J1.2, J6.A9 (VBUS), J6.B9 (VBUS), R1.2
unnamed: Conn1.3, IC1.19 (PB5)
unnamed: Conn1.4, IC1.17 (PB3)
unnamed: C1.1, Conn1.5, IC1.1 (PC6/~RESET), R1.1
unnamed: FB1.1, J4.4
unnamed: FB2.1, J4.1
unnamed: FB3.1, J4.2
unnamed: FB4.1, J4.3
unnamed: FB5.1, J3.R
unnamed: FB6.1, J3.T
unnamed: FB7.1, J3.S
unnamed: FB8.1, J5.R, J5.T
unnamed: C2.1, IC1.21 (AREF)
unnamed: IC1.14 (PB0), R11.1
unnamed: IC1.15 (PB1), R2.1
unnamed: IC1.16 (PB2), R3.1
unnamed: F1.1, IC1.9 (PB6/XTAL1)
unnamed: F1.3, IC1.10 (PB7/XTAL2)
unnamed: C9.1, FB6.2, IC1.2 (PD0)
unnamed: C12.1, FB5.2, IC1.3 (PD1)
unnamed: IC1.11 (PD5), SW3.1
unnamed: IC1.12 (PD6), SW2.1
unnamed: IC1.13 (PD7), SW1.1
unnamed: C14.1, IC2.3 (+)
unnamed: C19.1, IC2.2 (-)
unnamed: IC2.1 (GAIN), R12.1
unnamed: J2.3, J5.RN, J5.TN
unnamed: J6.A5 (CC1), R15.2
unnamed: P1.3, R8.2
unnamed: Q1.2 (B), R10.2, R11.2
unnamed: C20.1, FB1.2, Q1.3 (C)
unnamed: R9.2, RV1.1
unnamed: R14.1, RV2.1

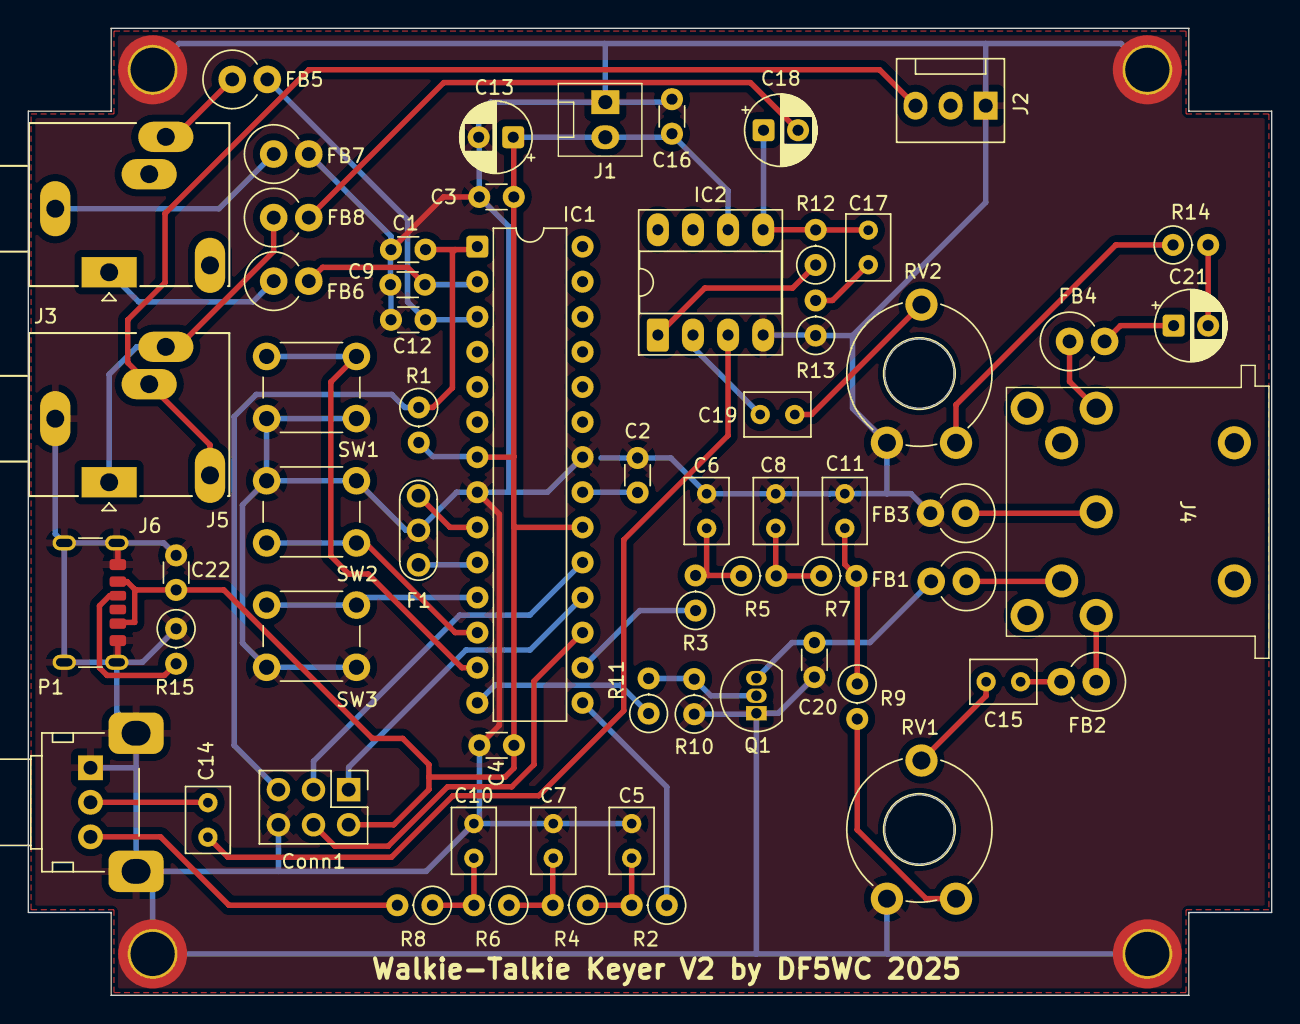
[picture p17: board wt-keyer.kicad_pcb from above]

Board: 2 copper layers, 90.0 x 70.0 mm, 66 parts (0 on the bottom side), 50 nets.

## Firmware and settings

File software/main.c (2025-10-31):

/*****************************************************************************/
/*                                                                           */
/*                                  main.c                                   */
/*                                                                           */
/*                     Dual tone generator main program                      */
/*                                                                           */
/*                                                                           */
/*                                                                           */
/* (C) 2025,      Ullrich von Bassewitz                                      */
/*                Roemerstrasse 52                                           */
/*                D-70794 Filderstadt                                        */
/* EMail:         uz@df5wc.org                                               */
/*                                                                           */
/*                                                                           */
/* This software is provided 'as-is', without any expressed or implied       */
/* warranty.  In no event will the authors be held liable for any damages    */
/* arising from the use of this software.                                    */
/*                                                                           */
/* Permission is granted to anyone to use this software for any purpose,     */
/* including commercial applications, and to alter it and redistribute it    */
/* freely, subject to the following restrictions:                            */
/*                                                                           */
/* 1. The origin of this software must not be misrepresented; you must not   */
/*    claim that you wrote the original software. If you use this software   */
/*    in a product, an acknowledgment in the product documentation would be  */
/*    appreciated but is not required.                                       */
/* 2. Altered source versions must be plainly marked as such, and must not   */
/*    be misrepresented as being the original software.                      */
/* 3. This notice may not be removed or altered from any source              */
/*    distribution.                                                          */
/*                                                                           */
/*****************************************************************************/



#include <stdbool.h>
#include <stdint.h>
#include <avr/io.h>
#include <avr/sleep.h>

/* wt-keyer */
#include "buttons.h"
#include "config.h"
#include "cw.h"
#include "cwmem.h"
#include "keyer.h"
#include "rigctrl.h"
#include "timer.h"
#include "tone.h"
#include "version.h"



/*****************************************************************************/
/*                             Helper functions                              */
/*****************************************************************************/



static void SetupIO(void)
/* Setup I/O stuff */
{
    /* IO Ports: PB0 and PB1/PB2 (= OC1A/OC1B) are outputs */
    DDRB = 0x07;

    /* Port C is currently unused and configured as input */
    DDRC = 0x00;
    PORTC = 0x00;       /* Tri-state port C */

    /* Port D is an input. Used bits are PD0/PD1/PD5/PD6/PD7 */
    DDRD = 0x00;
    PORTD = 0xE3;       /* Activate pullups for all used port bits */

    /* Setup tone generation */
    SetupTone();

    /* Setup the timer ticker */
    SetupTimer();
}



/*****************************************************************************/
/*                               Main program                                */
/*****************************************************************************/



int main(void)
{
    /* Initialize I/O and modules */
    SetupIO();
    SetupCw();
    SetupCwMem();
    SetupKeyer();
    SetupRigCtrl();

    /* Run forever */
    while (1) {
        /* Run the keyer. If it is idle, handle switches. React only on button
         * press, not release.
         */
        Keyer();
        uint8_t B;
        if ((B = (ChangedButtons & Buttons)) != BUTTON_NONE) {
            /* Keyer is idle. Force TX and memory play off, then handle
             * switches.
             */
            TxAbort();
            switch (B) {
                case BUTTON_C:
                    AbortPlayCwMem();
                    Configuration();
                    break;

                case BUTTON_1:
                    if (CwMemIsPlaying()) {
                        AbortPlayCwMem();
                    } else {
                        StartPlayCwMem(CWMEM_1);
                    }
                    break;

                case BUTTON_2:
                    if (CwMemIsPlaying()) {
                        AbortPlayCwMem();
                    } else {
                        StartPlayCwMem(CWMEM_2);
                    }
                    break;

                default:
                    /* Ignore other button combinations */
                    break;
            }
            /* Reinitialize keyer and buffer */
            ResetKeyer();
        } else {
            /* Play cw memories if active */
            if (CwMemIsPlaying()) {
                /* Allow aborting with the paddle or straight key. Beware: If
                 * a straight key is used, dah may be tied to ground.
                 */
                if (Dit(Keys) || (!StraightKey && Dah(Keys))) {
                    AbortPlayCwMem();
                } else {
                    PlayCwMem();
                }
            }

            /* Send elements read by the keyer */
            TxSend();
        }

        /* Clear changed buttons and wait for the next timer interrupt */
        ChangedButtons = 0;
        sleep_cpu();
    }
}

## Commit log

2025-10-12 Added the current state of the project.
    [wt-keyer-case-button.stl, wt-keyer-case-label-1.stl, wt-keyer-case-label-2.stl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]
2025-10-12 Added the schematics as PDF.
2025-10-12 Added a note about problems with the boards under "known problems".
2025-10-22 Remove the paragraph that talks about a hissing sound. It comes from the 5V power supply, not the keyer itself.
2025-10-31 Updated the files for V2 of the walkie-talkie keyer.
    [wt-keyer-button-label-1.stl, wt-keyer-button-label-2.stl, wt-keyer-button-label-c.stl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]
2025-11-01 Use the ATMega8L for less current consumption.
